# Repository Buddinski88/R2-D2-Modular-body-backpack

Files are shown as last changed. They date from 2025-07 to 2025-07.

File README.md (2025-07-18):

# R2-D2 Modular Body Backpack

## General motivation
- There are many good solutions for organizing all the control electronics for the whole selection of R2D2 bodys.
- However, none of these solutions fully met my requirements, so I designed my own interpretation of a [modular control unit](https://github.com/Buddinski88/R2-D2-Modular-control-unit).
- But so that I can also mount some components in the body, the **Modular Body Backpack** was created.

## Requirements
- The module must be completely removable as a single unit to allow work on it at the workbench.
  - Everything must be possible without any special tools, i.e., plug-and-play instead of screws (almost achieved)!
- The design must be modular, allowing it to be adapted to specific requirements.
- The design must be based on a grid (60x60mm) and offers panels ranging from `1x1` to `NxN`.

## Images

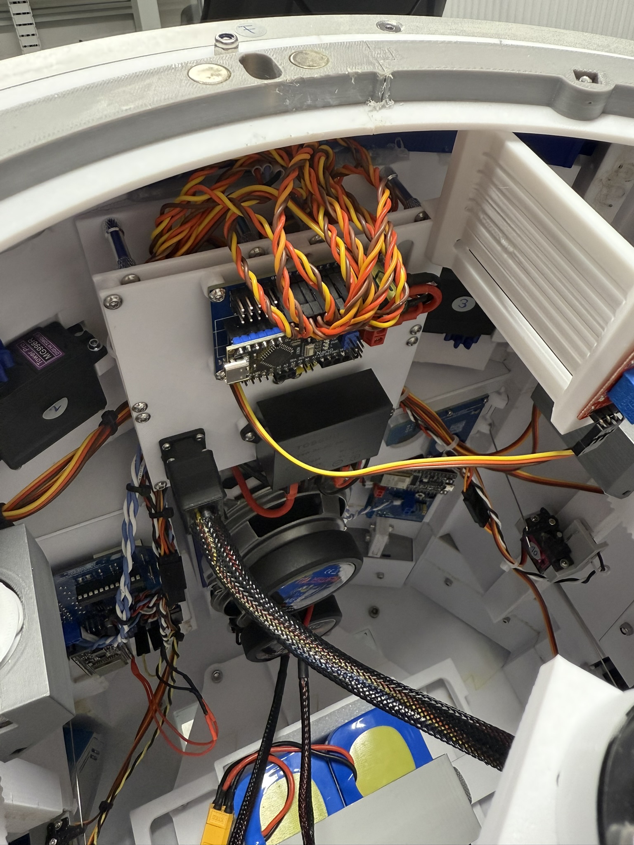
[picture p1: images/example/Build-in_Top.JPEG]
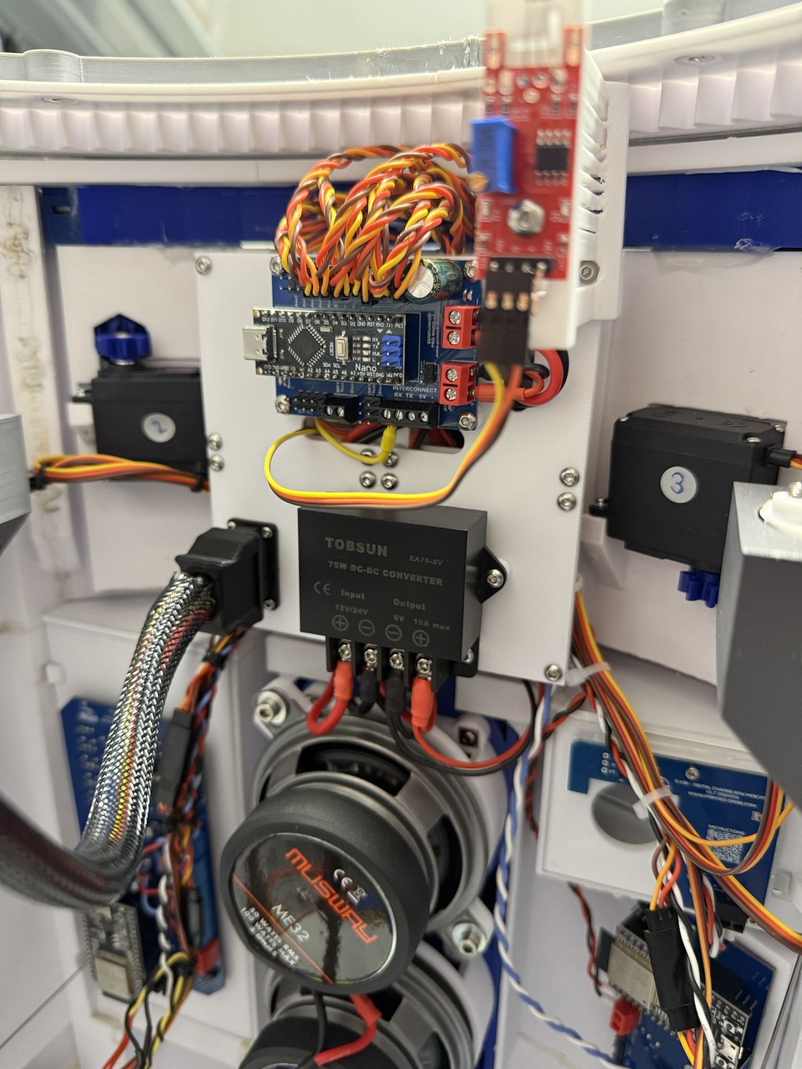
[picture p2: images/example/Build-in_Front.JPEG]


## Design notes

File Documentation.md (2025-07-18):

# Documentation Modular Body Backpack (MBB)

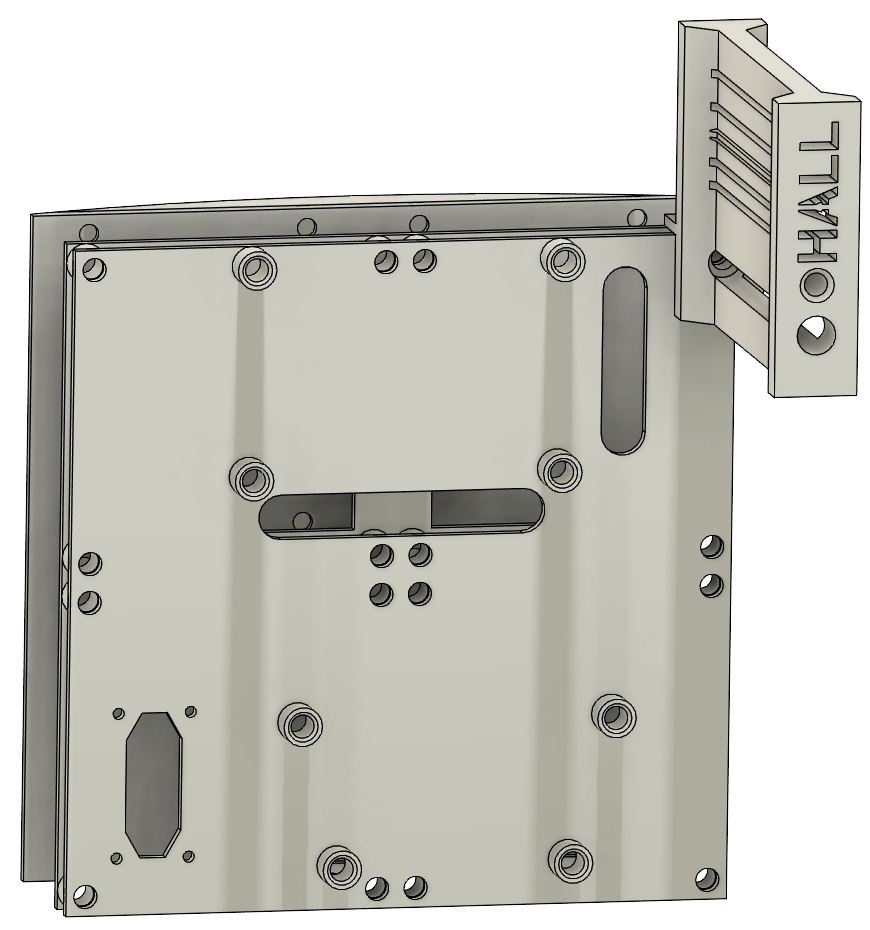
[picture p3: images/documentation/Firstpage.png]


<p style="text-align: center;">Version 1.0 created by Bastian Oelkuch with Fusion360</p>

# Table of content
- [Documentation Modular Body Backpack (MBB)](#documentation-modular-body-backpack-mbb)
- [Table of content](#table-of-content)
  - [General description and requirements](#general-description-and-requirements)
  - [Overview of the design](#overview-of-the-design)
    - [Frame](#frame-can-be-seen-as-assembly-steps)
    - [Panels](#panels)
  - [Parts list](#parts-list)
    - [Screws and Nuts](#screws-and-nuts)
    - [Threaded inserts, Standoffs \& Bearings](#threaded-inserts-standoffs--bearings)
    - [Connectors and Switches](#connectors)
    - [Boards](#boards)
  - [Assembly Instructions](#assembly-instructions)

<blockquote class="callout warning">
⚠️ <strong>WARNING:</strong> I am not a trained electrician and cannot take any responsibility for any damage or injury that may occur.
</blockquote>

<blockquote class="callout tip">
   🛠 <strong>TIP:</strong> Have a look at the <a href="https://github.com/Buddinski88/R2-D2-Modular-control-unit">R2-D2 Modular Control Unit</a> which is also called MCU if you want a flexible solution for the complete R2 electronics.
</blockquote>

## General description and requirements
- All files have numbers at the end `d1x1` means that the panel has a size of 60x60mm.

## Overview of the design

### Frame (can be seen as assembly steps)

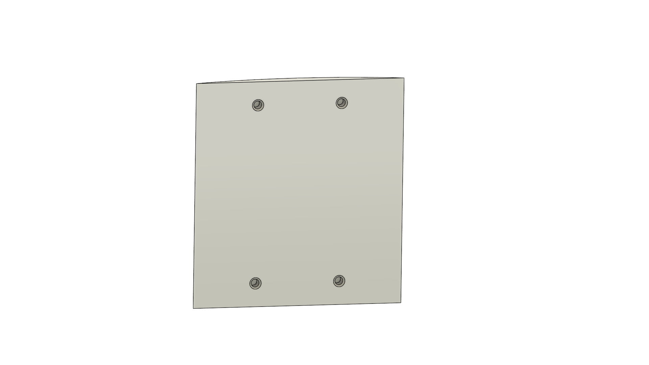
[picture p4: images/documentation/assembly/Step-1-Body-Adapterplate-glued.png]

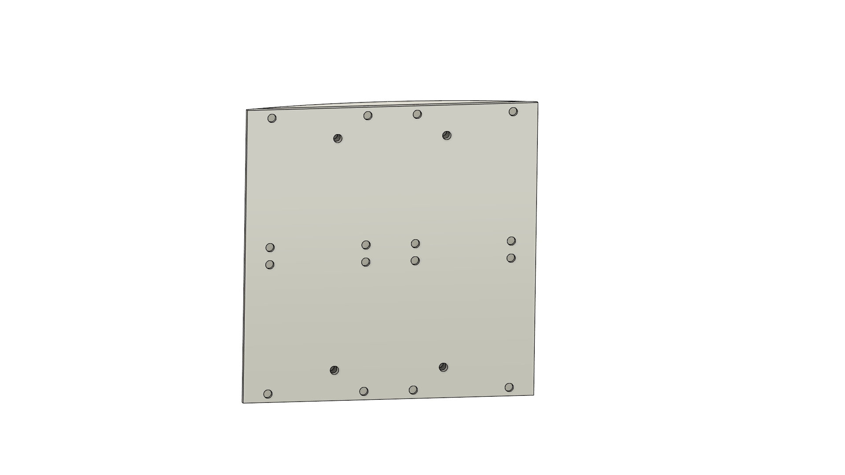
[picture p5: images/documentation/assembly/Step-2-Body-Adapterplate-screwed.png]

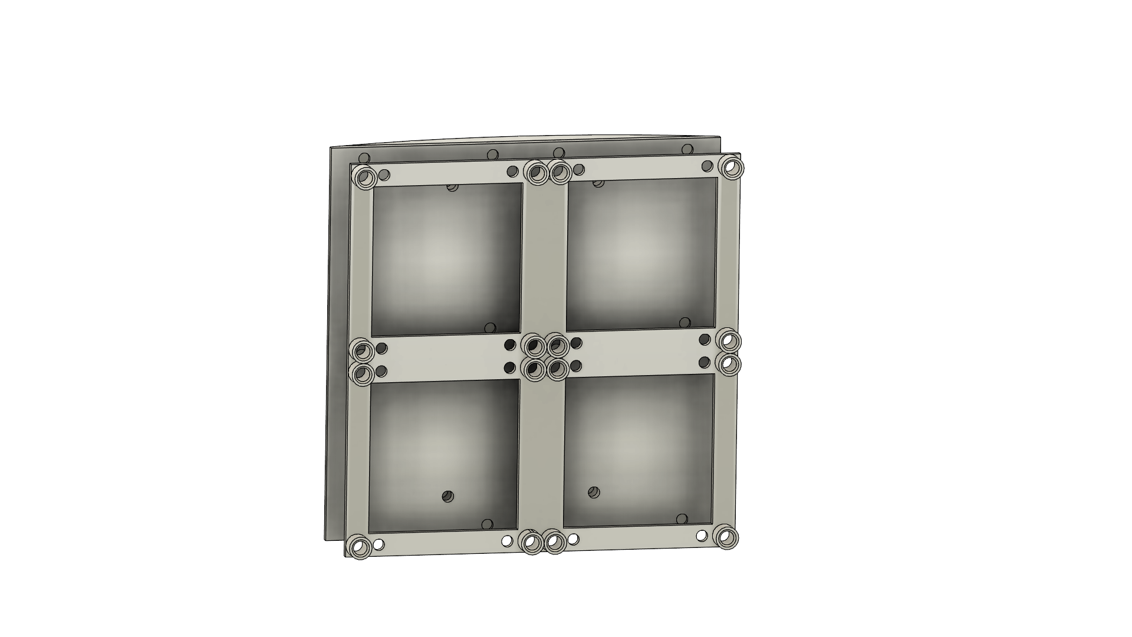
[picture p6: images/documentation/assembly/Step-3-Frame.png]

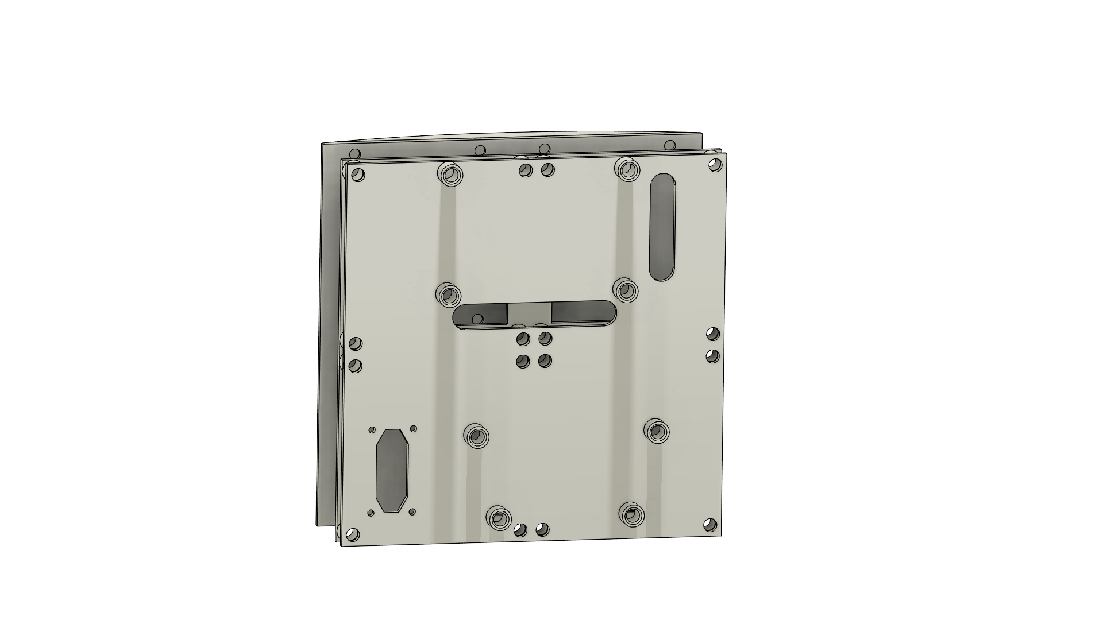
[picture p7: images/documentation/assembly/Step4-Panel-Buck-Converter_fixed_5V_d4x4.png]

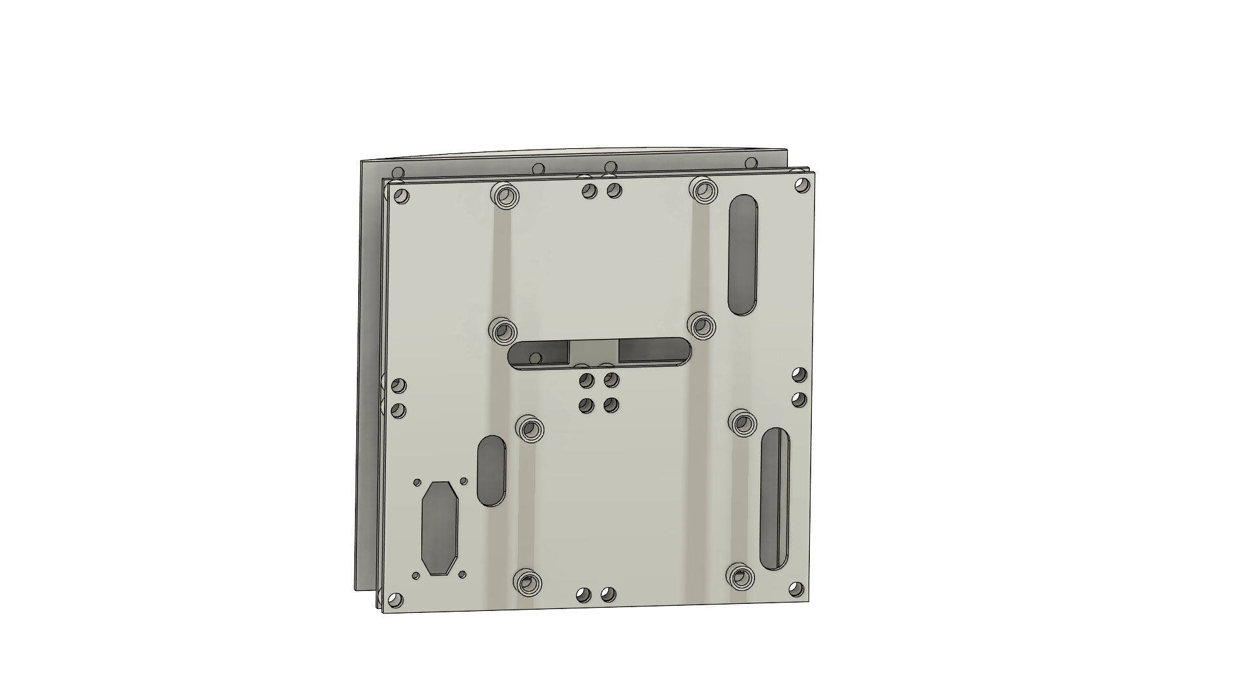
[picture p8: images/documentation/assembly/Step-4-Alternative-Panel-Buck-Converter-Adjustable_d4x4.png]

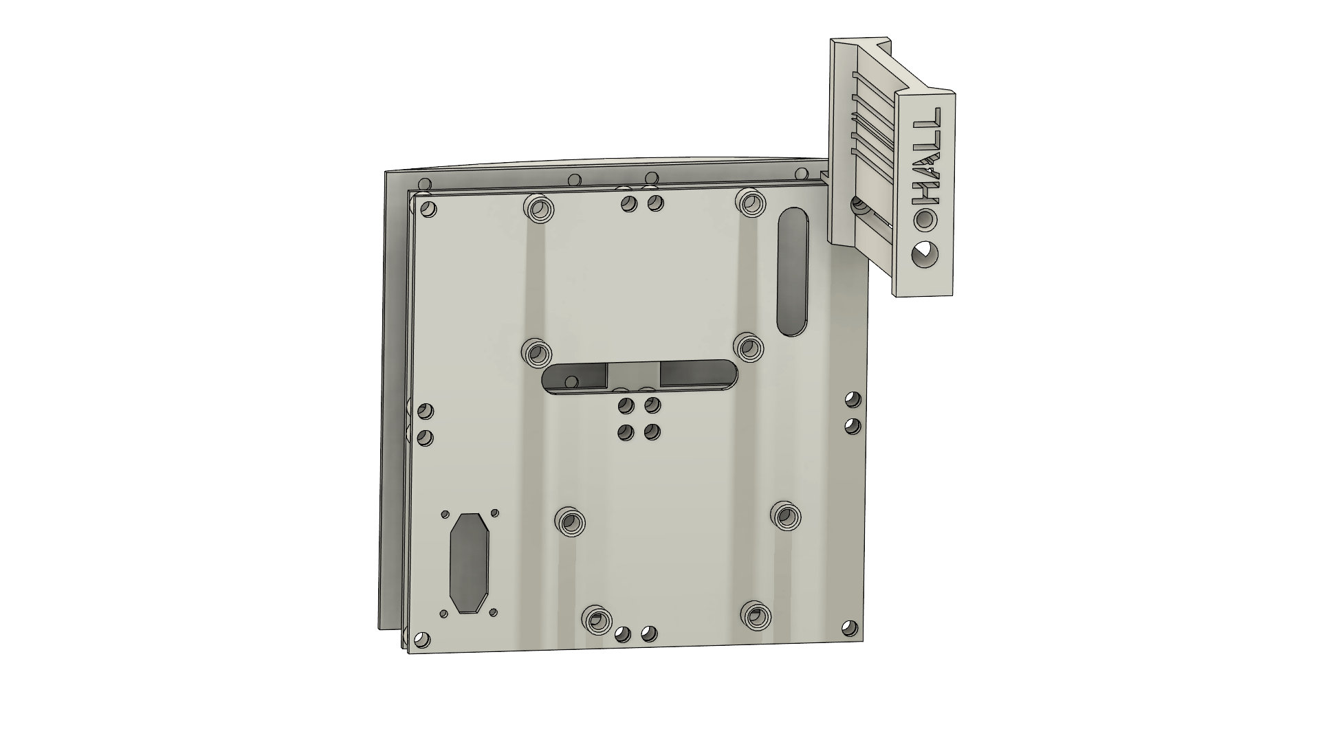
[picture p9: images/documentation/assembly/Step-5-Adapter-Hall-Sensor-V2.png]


### Panels

| Name | Screenshot |
| --- | --- |
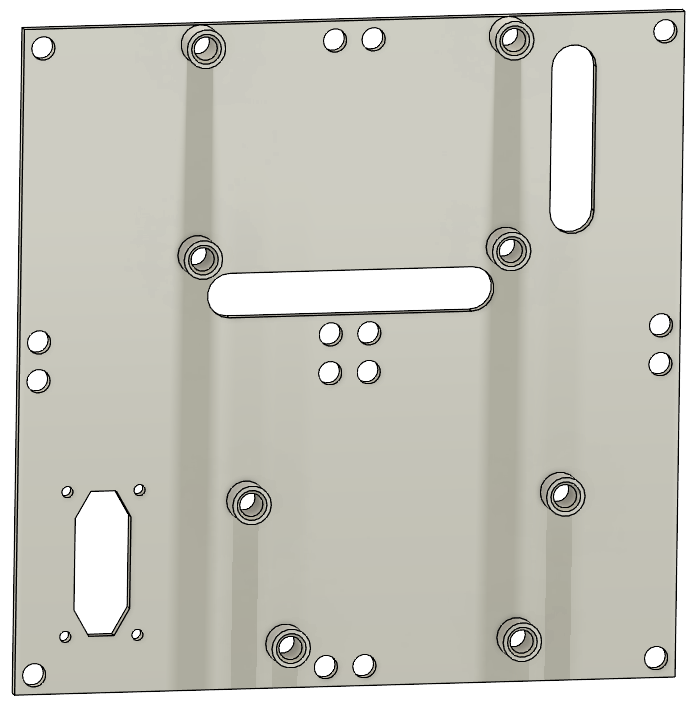
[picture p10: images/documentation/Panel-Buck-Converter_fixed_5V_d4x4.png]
| Panel-Buck-Converter_fixed_5V_d4x4.stl |  |
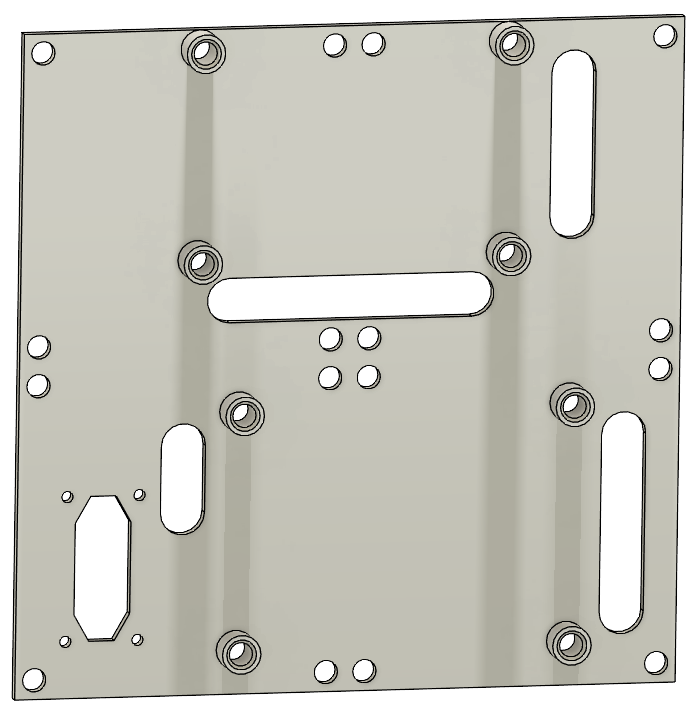
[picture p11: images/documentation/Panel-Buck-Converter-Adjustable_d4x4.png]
| Panel-Buck-Converter-Adjustable_d4x4.stl |  |
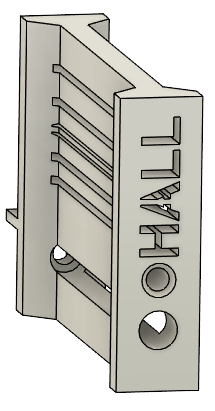
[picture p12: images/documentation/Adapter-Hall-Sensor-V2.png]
| Adapter-Hall-Sensor-V2.stl |  |

## Parts list

### Screws and Nuts

| Type | Quantity | Used for | Link |
| --- | --- | --- | ---- |
| **M2x10 mm Cylinder Head Screw** | **4** | Attaching MPX-like connector to printed panels | |
| **M3x6 mm Countersunk Head Screw** | **16**  | For connecting `Body-Adapterplate-glued.stl` and `Body-Adapterplate-screwed.stl` | |
| **M3x6 mm Pan Head Screw** | **29** | 16 for connecting `Frame.stl` and `Body-Adapterplate-screwed.stl` | |
| | | 4 for connecting the Panel to the Frame | |
| | | 4 for connection the Benduino Single to the panel | |
| | | 2-4 for attaching the Buck-Converter(s) to the panel | |
| **M3x12 mm Pan Head Screw** | **1** | 1 for connecting `Adapter-Hall-Sensor-V2.stl` to the frame/panel | |

### Threaded inserts, Standoffs & Bearings

| Type | Quantity | Used for | Link |
| --- | --- | --- | ---- |
| **M3x5.7 mm Threaded Insert** | **27**  | To fill all available inserts on the frame (additional inserts may be required based on panel used), the boards and hallsensor to the panel | [Amazon](https://www.amazon.de/gp/product/B08BCRZZS3) |
| **M3x25 mm Standoffs** | **16** | Connecting the `Body-Adapterplate-glued.stl` and `Body-Adapterplate-screwed.stl` | [AliExpress](https://de.aliexpress.com/item/1005003175580805.html) |

### Connectors

| Type | Quantity | Used for | Link |
| --- | --- | --- | ---- |
| **MPX-like Connector** | **1** | To provide a power connection with power and up to 6 data lines to the body | [AliExpress](https://de.aliexpress.com/item/1005001997107973.html) |

### Boards

| Type | Quantity | Used for | Link |
| --- | --- | --- | ---- |
| **5V 15A Buck Converter** | **1** | Power supply for 5V | [AliExpress](https://de.aliexpress.com/item/1005006506300187.html) |
| Altenative **5V 10A Buck Converter** | **1** | Power supply for 5V | [Amazon](https://www.amazon.de/dp/B09GLT7RVS) |
| **Benduino Single** | **1** | "The Brain for all Body related servos" | [printed-droid.com](https://shop.printed-droid.com/produkt/benduino-single-2024/) |
| **Hall-Sensor** | **1** | Will be provided with the AstroCan AutoDome Module | [printed-droid.com](https://shop.printed-droid.com/produkt/astrocan-autodome/) |

## Assembly instructions

1. Melt in four *M3x5.7 mm threaded inserts* to the `Body-Adapterplate-glued.stl`.
2. Glue with some 2k epoxy the `Body-Adapterplate-glued.stl` to the body (or just use some double-sided tape).
3. Screw the standoffs to the `Body-Adapterplate-screwed.stl`.
4. Screw the `Body-Adapterplate-screwed.stl` to the `Body-Adapterplate-glued.stl`.
5. Scree the `Frame.stl` to the `Body-Adapterplate-screwed.stl`.
6. Prepare the panel of your choice and screw it to the `Frame.stl`.
7. Now you can add the boards and the hall   sensor to finish the assembly.

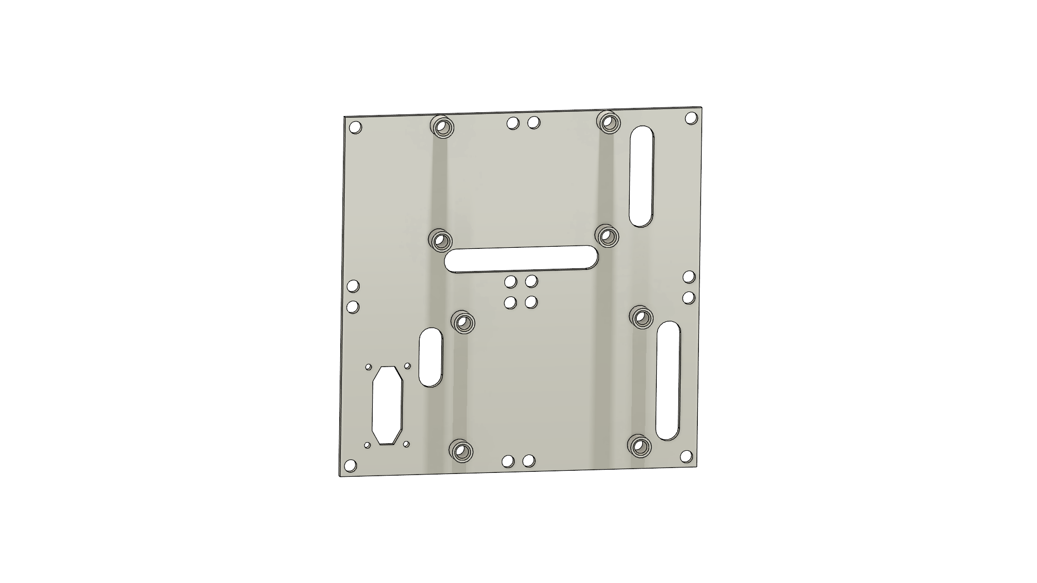
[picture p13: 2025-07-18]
images/documentation/fullsize/Panel-Buck-Converter-Adjustable_d4x4.png

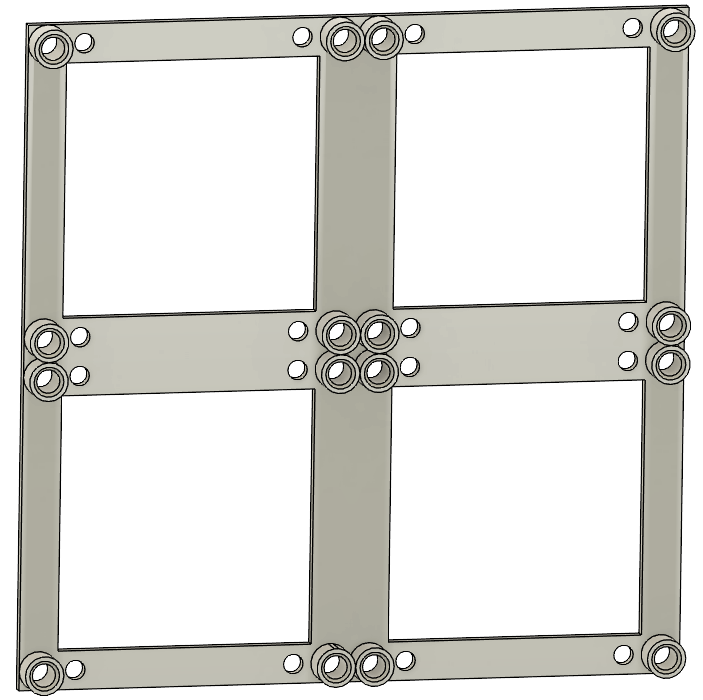
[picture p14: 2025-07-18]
images/documentation/Frame.png

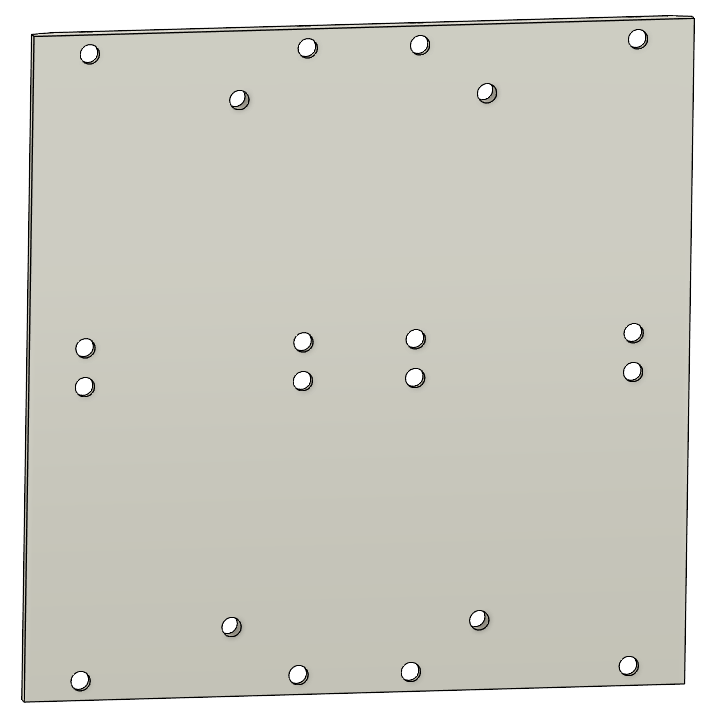
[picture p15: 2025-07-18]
images/documentation/Board-Adapterplate-screwed.png

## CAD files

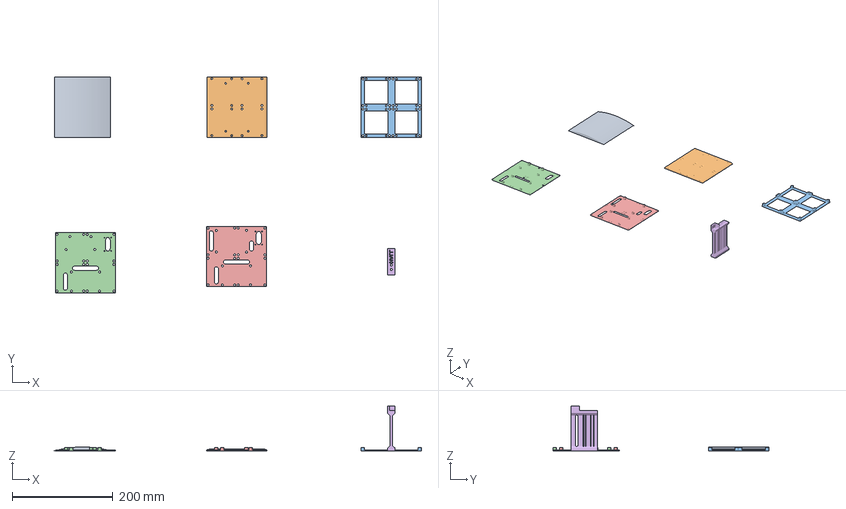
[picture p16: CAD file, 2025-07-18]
bambulab-x1c-print-profile.3mf
730.2 x 429.3 x 89.0 mm
Body-Adapterplate-glued.stl
Board-Adapterplate-screwed.stl
Frame.stl
Panel-Buck-Converter_fixed_5V_d4x4.stl
Panel-Buck-Converter-Adjustable_d4x4.stl
Adapter-Hall-Sensor-V2.stl

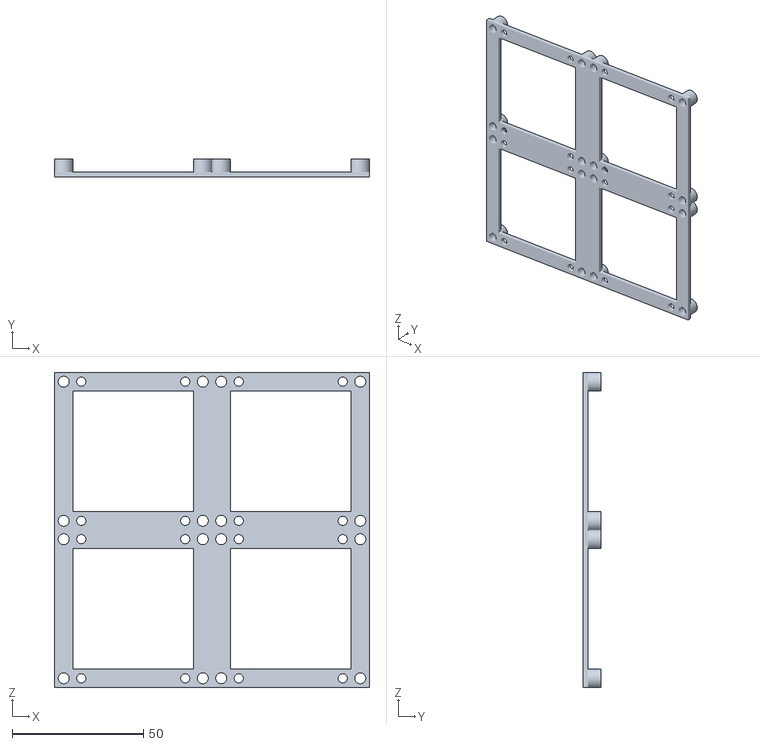
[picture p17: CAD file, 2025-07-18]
print-files/Frame.stl
120.0 x 7.00 x 120.0

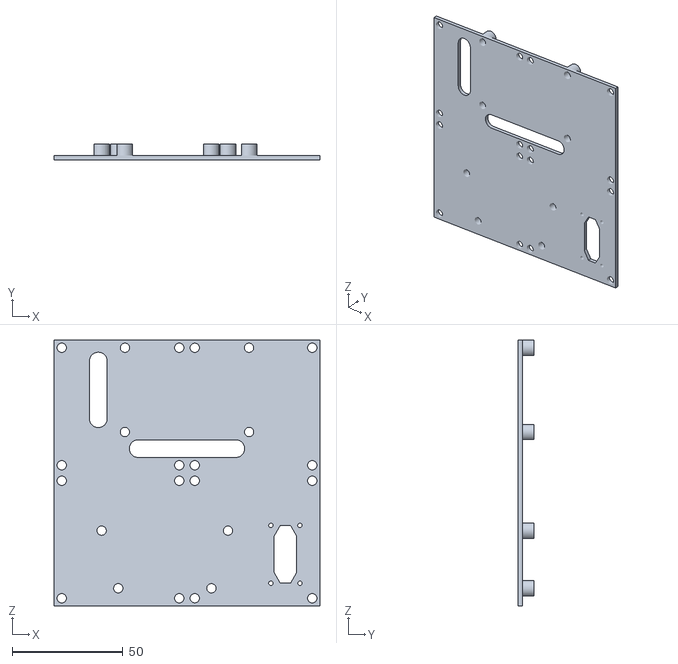
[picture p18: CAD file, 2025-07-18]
print-files/Panel-Buck-Converter_fixed_5V_d4x4.stl
120.0 x 7.00 x 120.0

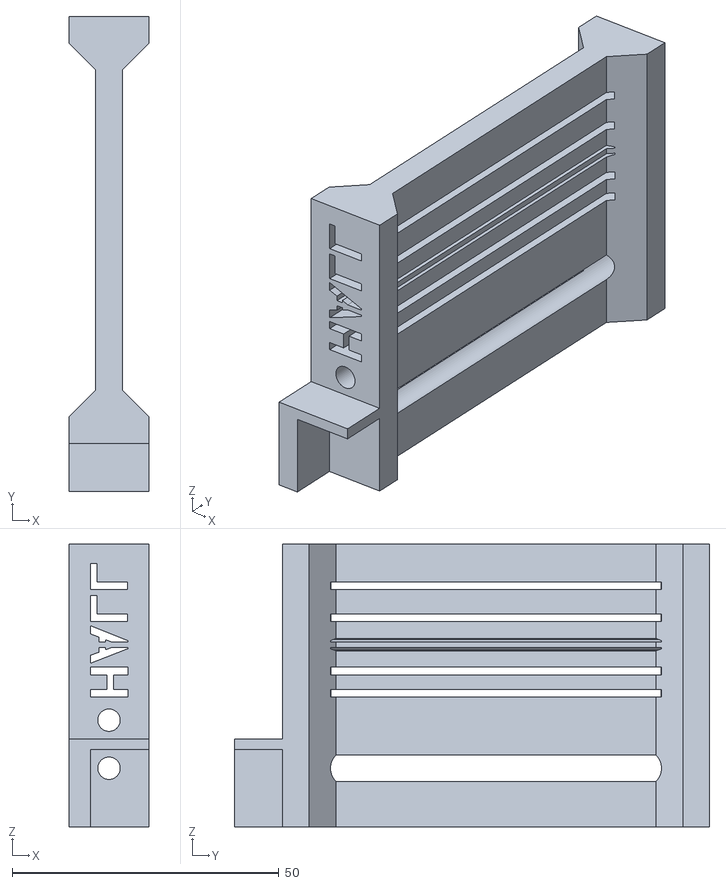
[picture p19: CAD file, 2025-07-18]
print-files/Adapter-Hall-Sensor-V2.stl
15.0 x 89.0 x 53.0

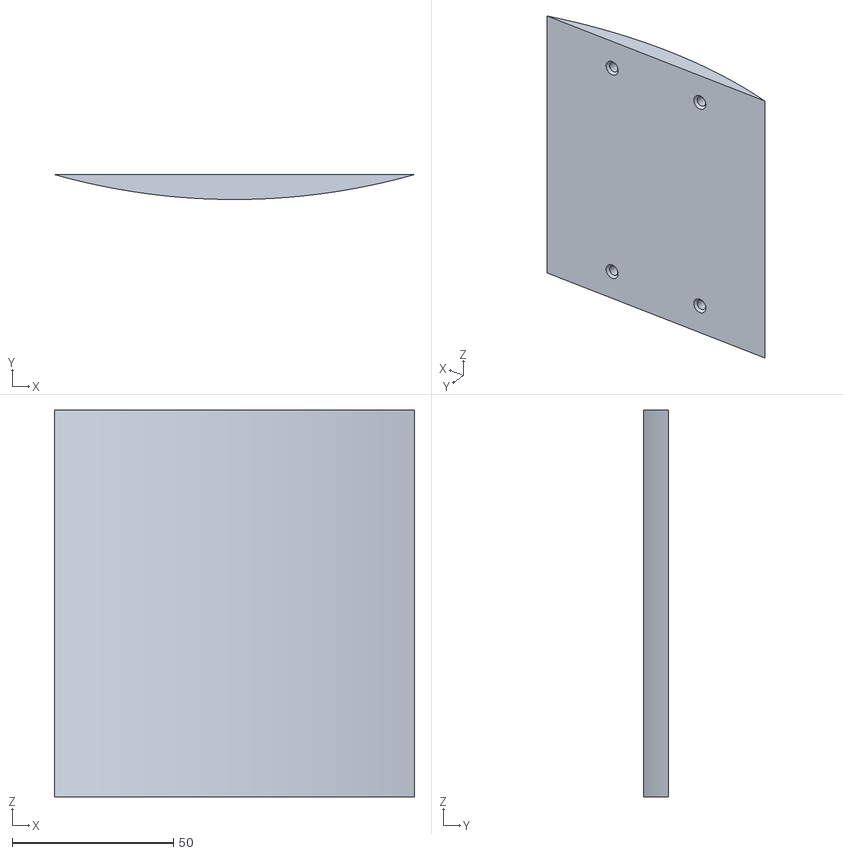
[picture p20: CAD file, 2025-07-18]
print-files/Body-Adapterplate-glued.stl
111.7 x 7.73 x 120.0

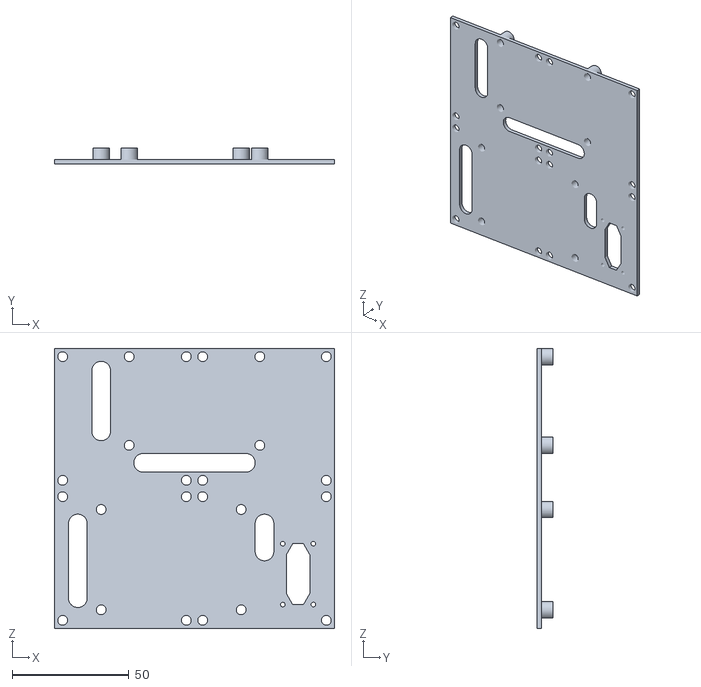
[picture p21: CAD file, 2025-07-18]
print-files/Panel-Buck-Converter-Adjustable_d4x4.stl
120.0 x 7.00 x 120.0

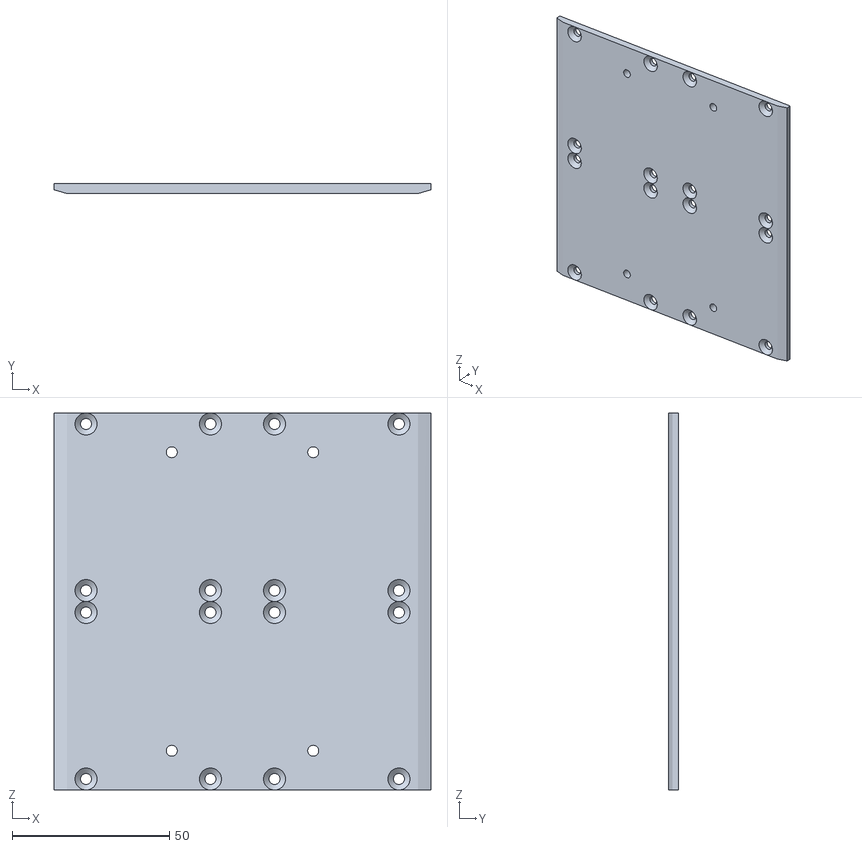
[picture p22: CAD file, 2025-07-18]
print-files/Board-Adapterplate-screwed.stl
120.0 x 3.22 x 120.0
